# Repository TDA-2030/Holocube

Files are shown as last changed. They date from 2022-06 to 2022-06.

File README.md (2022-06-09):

# Holocubic

用 ESP32-S3 重新设计的版本

## 板载资源

- [ESP32-S3FN8 / ESP32-S3FH4R2](https://www.espressif.com/sites/default/files/documentation/esp32-s3_datasheet_en.pdf)
- [WM8978](https://pdf1.alldatasheet.com/datasheet-pdf/view/96647/WOLFSON/WM8978.html) 音频 Codec
- 单声道模拟麦克风
- MPU6050 惯性传感器

## PCB 

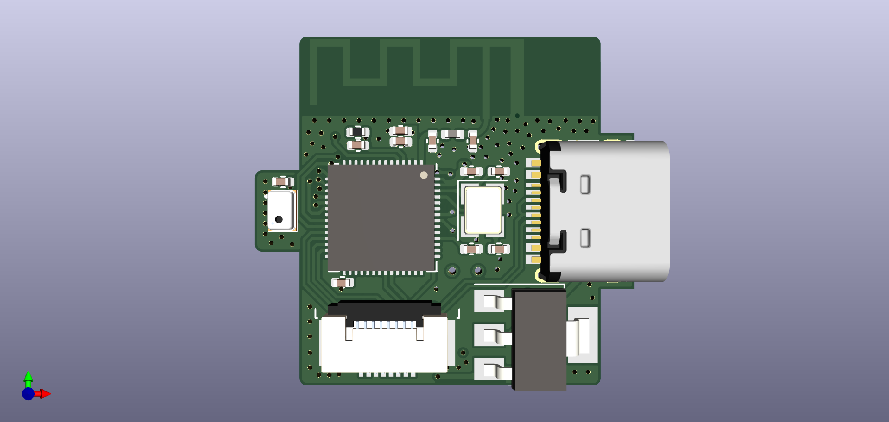
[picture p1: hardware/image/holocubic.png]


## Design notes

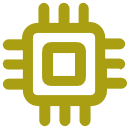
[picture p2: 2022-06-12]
firmware/main/HoloCubic_AIO/Image/app_hardware_info.png

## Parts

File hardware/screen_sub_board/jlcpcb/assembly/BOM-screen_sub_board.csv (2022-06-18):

Comment | Designator | Footprint | LCSC
S8050 | Q1 | SOT-23
22R | R1 | R_0402_1005Metric
Conn_01x08_MountingPin | J1 | TE_0-1734839-8_1x08-1MP_P0.5mm_Horizontal
1uf | C1 | C_0402_1005Metric
LCD_1.3_240x240_ST7789 | U1 | LCD_1.3_240x240_ST7789
10K | R2 | R_0402_1005Metric
1uf | C2 | C_0402_1005Metric

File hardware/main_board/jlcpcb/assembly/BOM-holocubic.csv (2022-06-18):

Comment | Designator | Footprint | LCSC
1uf | C25 | C_0402_1005Metric
0.1uf | C26 | C_0402_1005Metric
2.2uf | C17 | C_0402_1005Metric
AMS1117-3.3 | U1 | SOT-223-3_TabPin2
1uf | C10 | C_0402_1005Metric
Antenna_Shield | AE1 | Texas_SWRA117D_2.4GHz_Left
TBD | C8 | C_0402_1005Metric
TBD | C7 | C_0402_1005Metric
40MHz | Y1 | Crystal_SMD_3225-4Pin_3.2x2.5mm
0.1uf | C3 | C_0402_1005Metric
10pf | C9 | C_0402_1005Metric
10pf | C11 | C_0402_1005Metric
USB_C_Receptacle_USB2.0 | J2 | USB_C_Receptacle_HRO_TYPE-C-31-M-12
TBD | L1 | L_0402_1005Metric
ESP32-S3 | U2 | QFN-56-1EP_7x7mm_P0.4mm_EP5.6x5.6mm
10uf | C2 | C_0603_1608Metric
TFT_LCD | J1 | TE_0-1734839-8_1x08-1MP_P0.5mm_Horizontal
10k | R1 | R_0402_1005Metric
0.1uf | C5 | C_0402_1005Metric
Microphone_MEMS | MK1 | MEMS_MIC_2.75x1.85x0.9mm
0.1uf | C6 | C_0402_1005Metric
10uf | C4 | C_0603_1608Metric
1uf | C14 | C_0402_1005Metric
2.2uf | C21 | C_0402_1005Metric
TestPoint | TP8 | TestPoint_Pad_D1.0mm
TestPoint | TP7 | TestPoint_Pad_D1.0mm
TestPoint | TP3 | TestPoint_Pad_D1.0mm
0Ω | R4 | R_0402_1005Metric
TestPoint | TP4 | TestPoint_Pad_D1.0mm
2.2uf | C19 | C_0402_1005Metric
WM8978 | U3 | QFN-32-1EP_5x5mm_P0.5mm_EP3.3x3.3mm
2.2uf | C23 | C_0402_1005Metric
1uf | C13 | C_0402_1005Metric
5.1k | R2 | R_0402_1005Metric
2.2uf | C20 | C_0402_1005Metric
TestPoint | TP6 | TestPoint_Pad_D1.0mm
TestPoint | TP5 | TestPoint_Pad_D1.0mm
1uf | C15 | C_0402_1005Metric
1uf | C16 | C_0402_1005Metric
10uf | C1 | C_0603_1608Metric
10pf | C12 | C_0402_1005Metric
2.2uf | C22 | C_0402_1005Metric
MPU-6050 | U4 | InvenSense_QFN-24_4x4mm_P0.5mm
TestPoint | TP1 | TestPoint_Pad_D1.0mm
5.1k | R3 | R_0402_1005Metric
TestPoint | TP2 | TestPoint_Pad_D1.0mm
1uf | C24 | C_0402_1005Metric
1uf | C18 | C_0402_1005Metric

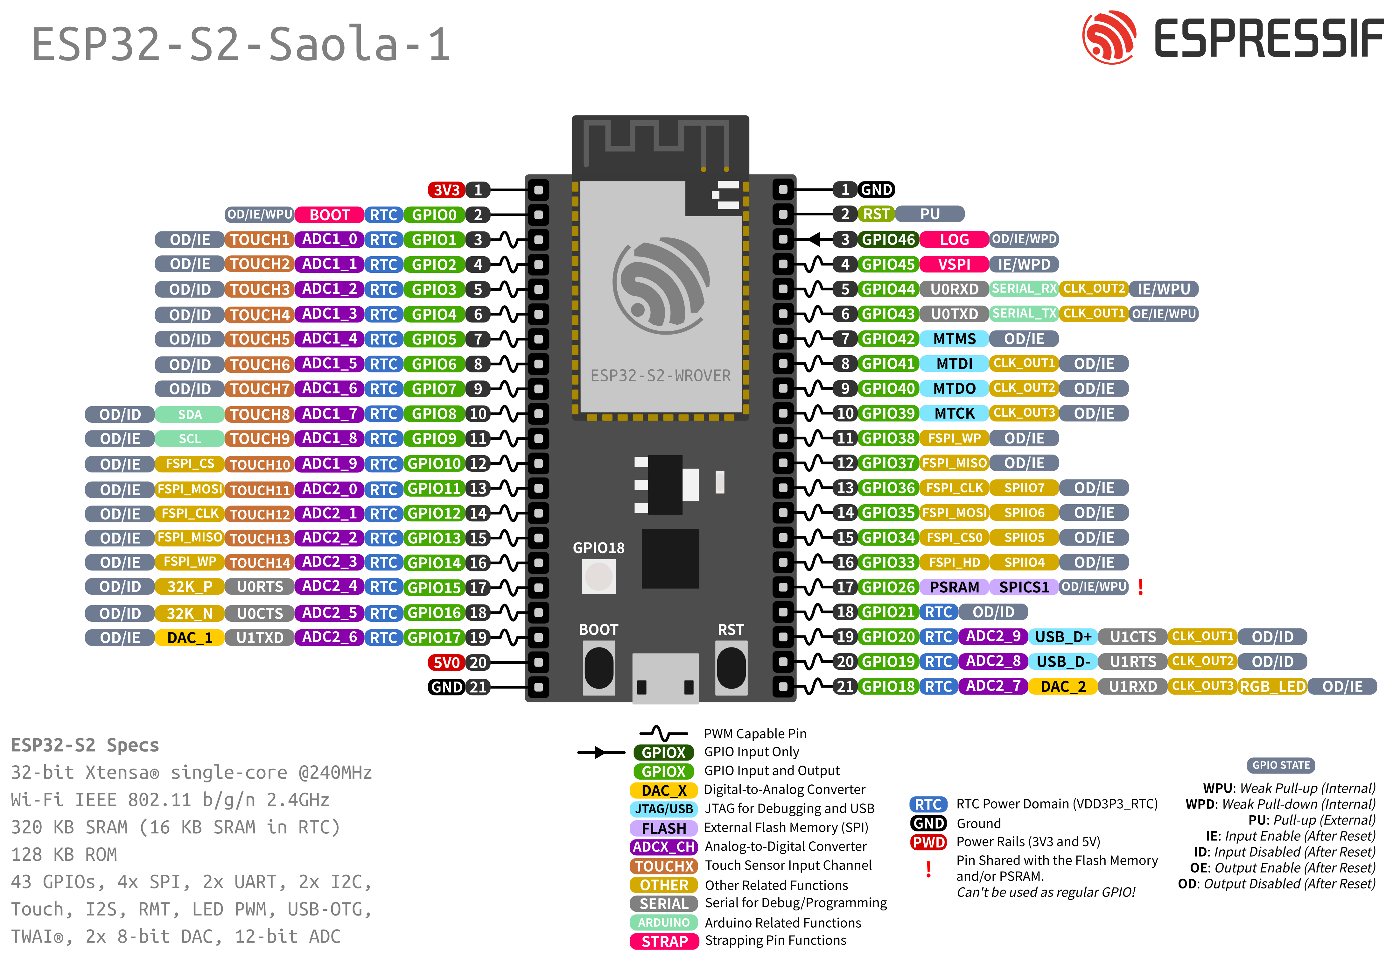
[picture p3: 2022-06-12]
firmware/components/arduino-esp32/docs/source/_static/esp32-s2_saola1_pinlayout.png

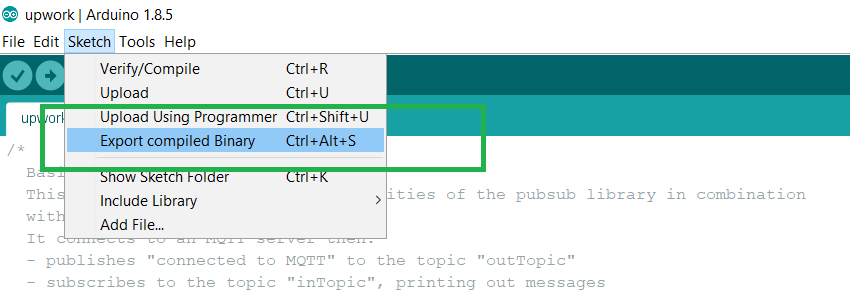
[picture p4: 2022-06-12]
firmware/components/arduino-esp32/docs/source/_static/ota_export_to_binary.png

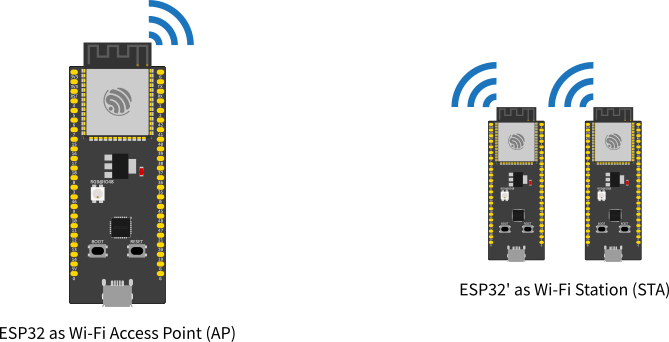
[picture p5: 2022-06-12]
firmware/components/arduino-esp32/docs/source/_static/wifi_esp32_ap.png

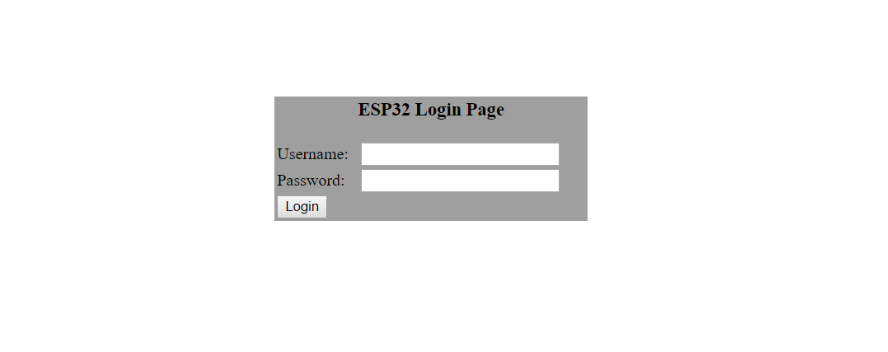
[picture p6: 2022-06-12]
firmware/components/arduino-esp32/docs/source/_static/ota_esp32_login.png

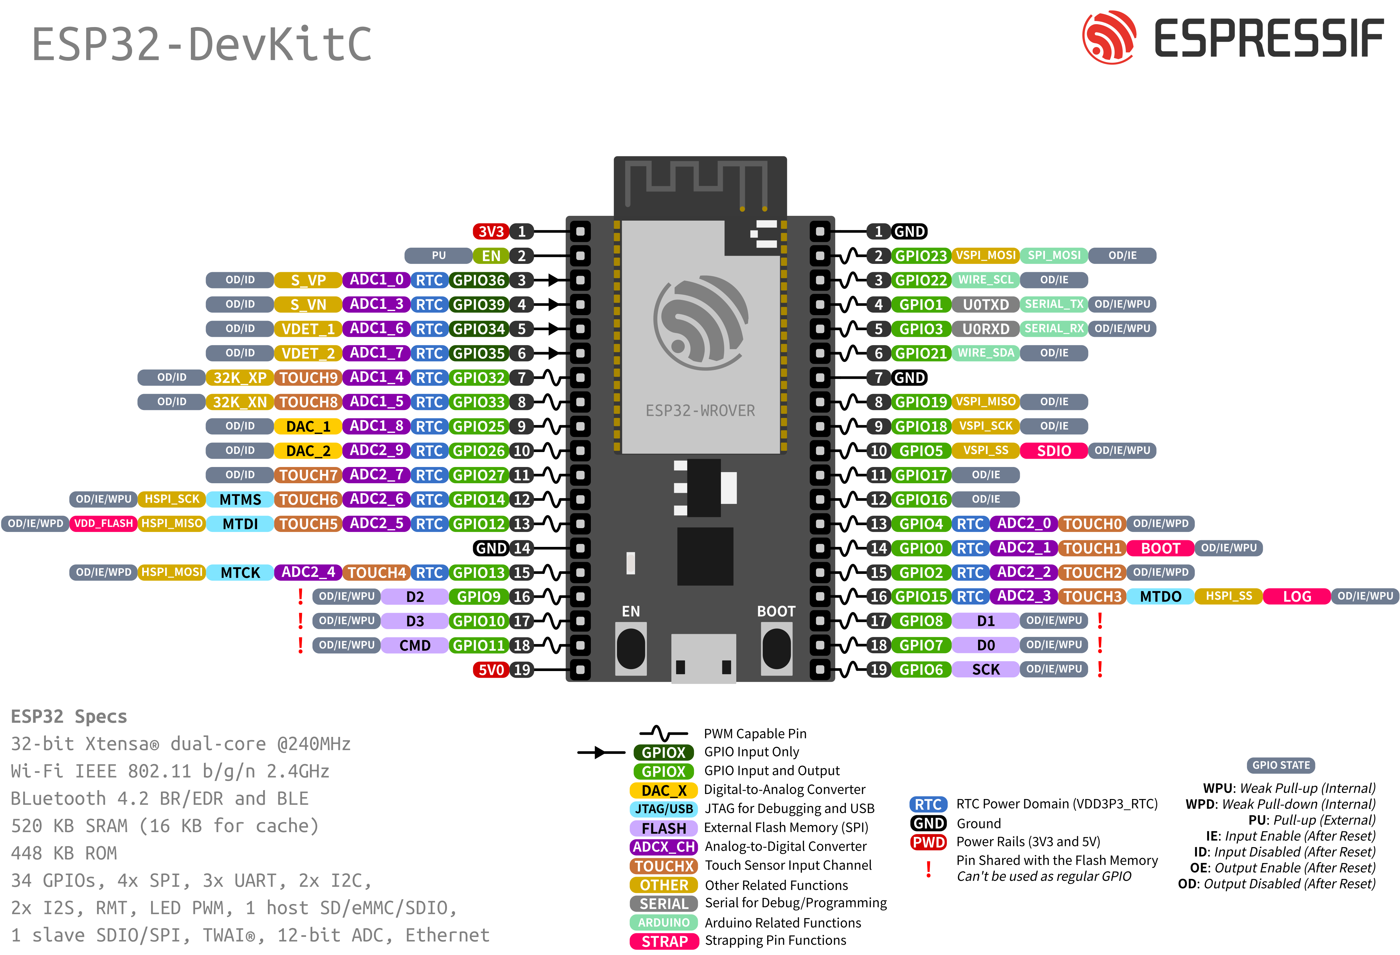
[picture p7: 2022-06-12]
firmware/components/arduino-esp32/docs/source/_static/esp32_devkitC_pinlayout.png

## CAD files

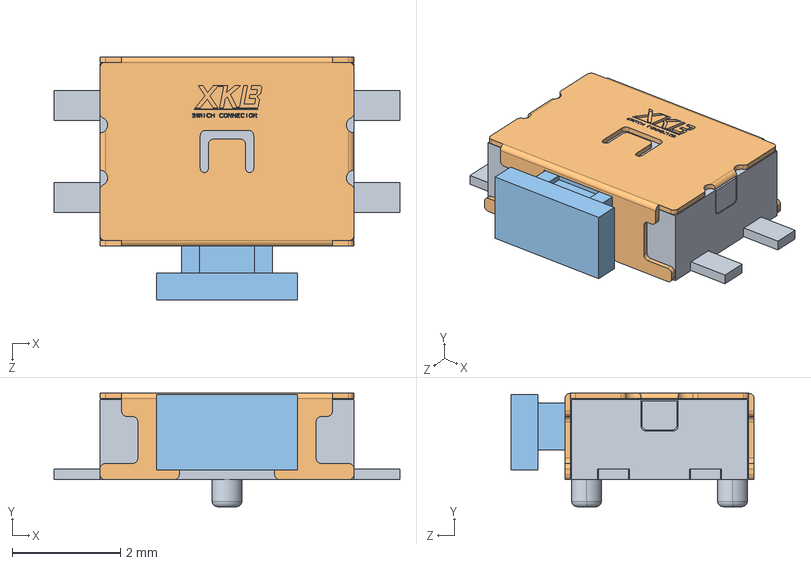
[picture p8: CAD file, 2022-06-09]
hardware/main_board/my-kicad-lib/3d/ts-1186d-c-a.STEP
6.40 x 2.10 x 4.50 mm
ts-1186d-c-a_01
ts-1186d-c-a_02
ts-1186d-c-a_03

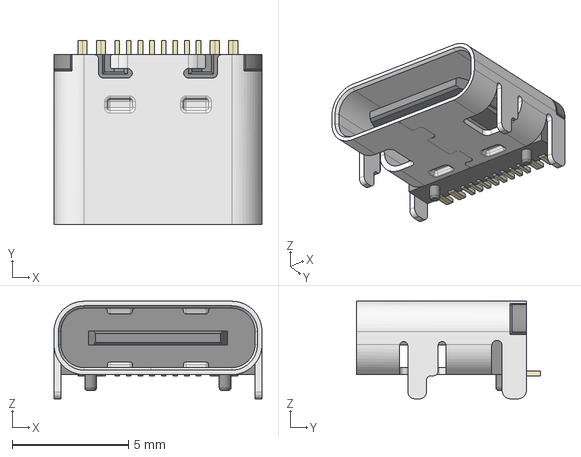
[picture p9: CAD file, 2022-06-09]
hardware/main_board/my-kicad-lib/3d/HRO_TYPE-C-31-M-12.step
8.95 x 7.90 x 4.20 mm

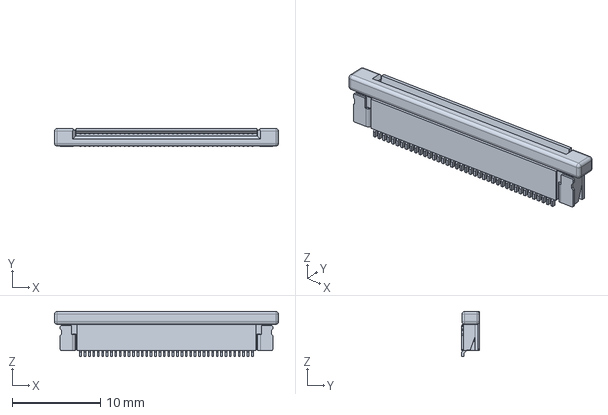
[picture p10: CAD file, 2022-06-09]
hardware/main_board/my-kicad-lib/3d/c-4-1734839-0-c-3d.stp
25.4 x 2.05 x 5.11 mm

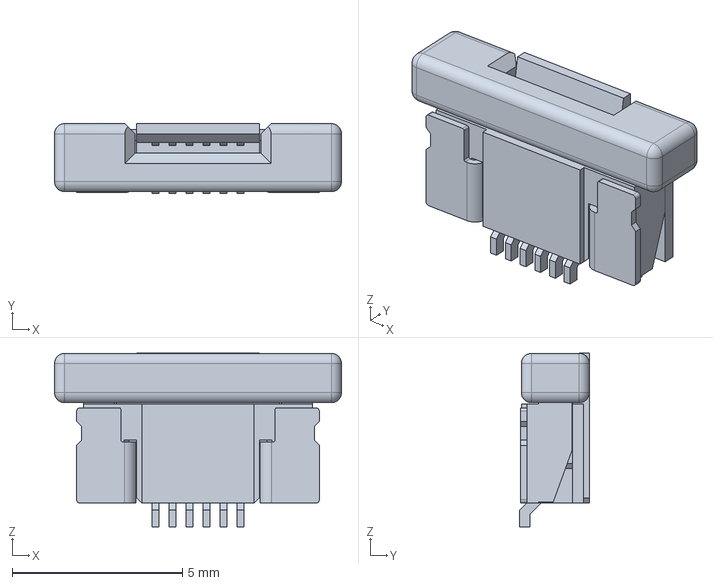
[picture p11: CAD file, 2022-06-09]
hardware/main_board/my-kicad-lib/3d/c-1734839-6-c-3d.stp
8.43 x 2.05 x 5.11 mm

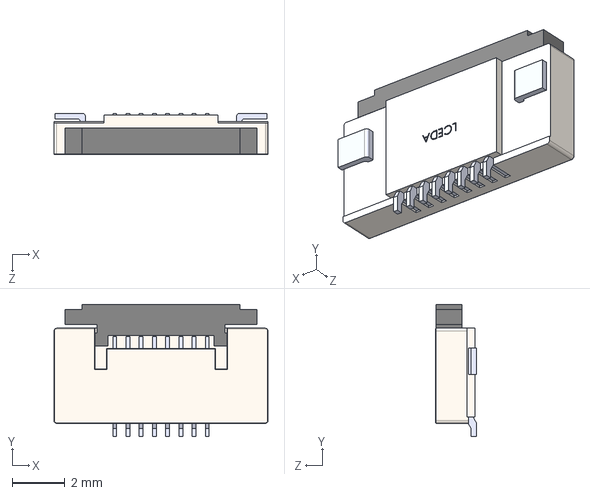
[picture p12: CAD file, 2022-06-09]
hardware/main_board/my-kicad-lib/3d/fpc-8p-0.5mm.STEP
8.10 x 5.00 x 1.55 mm

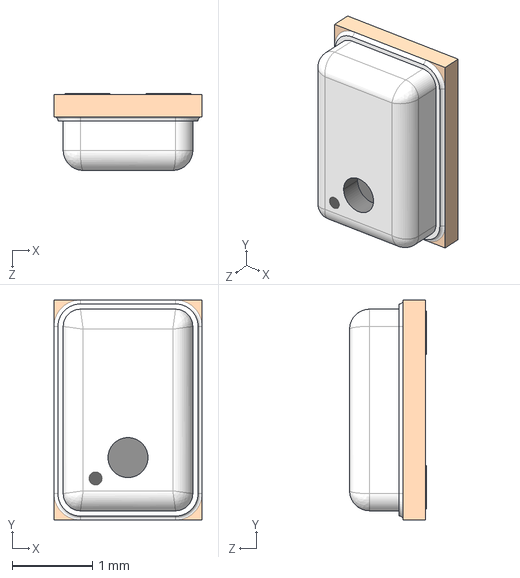
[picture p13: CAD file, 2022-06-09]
hardware/main_board/my-kicad-lib/3d/MEMS_MIC_2.75x1.85x0.95mm.STEP
1.85 x 2.75 x 0.96 mm

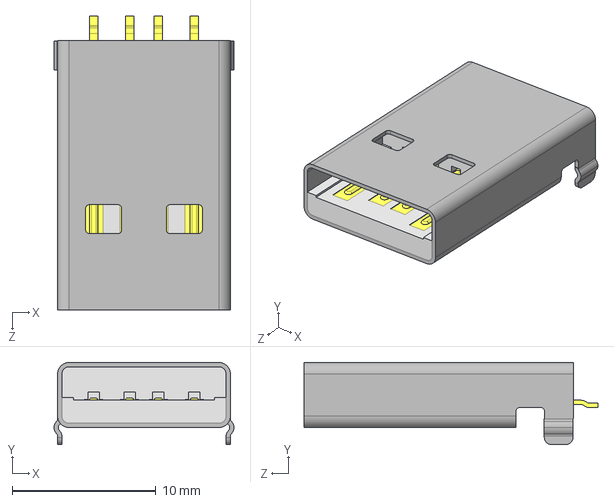
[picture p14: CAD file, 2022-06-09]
hardware/main_board/my-kicad-lib/3d/USB-AM-S-F-B-TH.STEP
12.5 x 5.70 x 20.4 mm

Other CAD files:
firmware/components/libjpeg/jpeg-9a/jdosamsc.obj
firmware/components/libjpeg/jpeg-9a/jdosabcc.obj

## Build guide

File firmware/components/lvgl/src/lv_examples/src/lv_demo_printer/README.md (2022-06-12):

# Printer demo

## Overview
A printer example created with LVGL. This demo is optmized for 800x480 resolution and among many others it demonstrates custom theme creation, style transitions and animations. 

The demo uses some images with 32 bit color depth they require ~1.6 MB flash. With 16 bit color depth ~900KB is required for the images.

Printer demo with LVGL embedded GUI library

## Run the demo
- In `lv_ex_conf.h` set `LV_USE_DEMO_PRINTER 1`
- After `lv_init()` and initializing the drivers call `lv_demo_printer()`

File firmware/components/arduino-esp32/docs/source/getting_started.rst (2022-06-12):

###############
Getting Started
###############

About Arduino ESP32
-------------------

Welcome to the Arduino ESP32 support documentation! Here you will find important information on how to use the project.

First Things First
------------------

.. note::
    Before continuing, we must be clear that this project is supported by `Espressif Systems`_ and the community.
    Everyone is more than welcome to contribute back to this project.

ESP32 is a single 2.4 GHz Wi-Fi-and-Bluetooth SoC (System On a Chip) designed by `Espressif Systems`_.

ESP32 is designed for mobile, wearable electronics, and Internet-of-Things (IoT) applications. It features all the state-of-the-art characteristics 
of low-power chips, including fine-grained clock gating, multiple power modes,and dynamic power scaling. For instance, in a low-power IoT sensor 
hub application scenario, ESP32 is woken-up periodically and only when a specified condition is detected. Low-duty cycle is used to minimize the 
amount of energy that the chip expends. 

The output of the power amplifier is also adjustable, thus contributing to an optimal trade-off between communication range, data rate and 
power consumption.

The ESP32 series is available as a chip or module.

.. _supported_socs:

Supported SoC's
---------------

Here are the ESP32 series supported by the Arduino-ESP32 project:

======== ====== =========== ===================================
SoC      Stable Development Datasheet
======== ====== =========== ===================================
ESP32    Yes    Yes         `ESP32`_
ESP32-S2 Yes    Yes         `ESP32-S2`_
ESP32-C3 Yes    Yes         `ESP32-C3`_
ESP32-S3 No     Yes         `ESP32-S3`_
======== ====== =========== ===================================

See `Boards <boards/boards.html>`_ for more details about ESP32 development boards.

Arduino Core Reference
----------------------

This documentation is built on the ESP32 and we are not going to cover the common Arduino API. To see the Arduino reference documentation, 
please consider reading the official documentation.

Arduino Official Documentation: `Arduino Reference`_.

Supported Operating Systems
---------------------------

+-------------------+-------------------+-------------------+
|     |       |       |
+-------------------+-------------------+-------------------+
| Windows           | Linux             | macOS             |
+-------------------+-------------------+-------------------+





Supported IDEs
---------------------------

Here is the list of supported IDE for Arduino ESP32 support integration.

+-------------------+-------------------+
|     |         |
+-------------------+-------------------+
| Arduino IDE       | PlatformIO        |
+-------------------+-------------------+




See `Installing Guides <installing.html>`_ for more details on how to install the Arduino ESP32 support.

Support
-------

This is an open project and it's supported by the community. Fell free to ask for help in one of the community channels.

Community
---------

The Arduino community is huge! You can find a lot of useful content on the Internet.
Here are some community channels where you may find information and ask for some help, if needed.

- `ESP32 Forum`_: Official Espressif Forum.
- `ESP32 Forum - Arduino`_: Official Espressif Forum for Arduino related discussions.
- `ESP32 Forum - Hardware`_: Official Espressif Forum for Hardware related discussions.
- `Gitter`_
- `Espressif MCUs (Discord)`_
- `ESP32 on Reddit`_

Issues Reporting
----------------

Before opening a new issue, please read this: 

Be sure to search for a similar reported issue. This avoids duplicating or creating noise in the GitHub Issues reporting.
We also have the troubleshooting guide to save your time on the most common issues reported by users.

For more details about creating new Issue, see the `Issue Template <https://github.com/espressif/arduino-esp32/blob/master/.github/ISSUE_TEMPLATE/Issue-report.yml>`_.

If you have any new idea, see the `Feature request Template <https://github.com/espressif/arduino-esp32/blob/master/.github/ISSUE_TEMPLATE/Feature-request.yml>`_.

First Steps
-----------

Here are the first steps to get the Arduino ESP32 support running.

To install Arduino-ESP32, please see the dedicated section on the Installation guide. We recommend you install it using the boards manager.

.. toctree::
    :maxdepth: 2
    
    How to Install <installing>
    Development Boards <boards/boards>

Examples
--------

After installing the toolchain into your environment, you will be able to see all the dedicated examples for the ESP32. These examples are located
in the examples menu or inside each library folder.

    https://github.com/espressif/arduino-esp32/tree/master/libraries

.. include:: common/datasheet.inc

Resources
---------

.. _Espressif Systems: https://www.espressif.com 
.. _Espressif Product Selector: https://products.espressif.com/
.. _Arduino.cc: https://www.arduino.cc/en/Main/Software
.. _Arduino Reference: https://www.arduino.cc/reference/en/
.. _ESP32 Forum: https://esp32.com
.. _ESP32 Forum - Arduino: https://esp32.com/viewforum.php?f=19
.. _ESP32 Forum - Hardware: https://esp32.com/viewforum.php?f=12
.. _Gitter: https://gitter.im/espressif/arduino-esp32
.. _Adafruit (Discord): https://discord.gg/adafruit
.. _Espressif MCUs (Discord): https://discord.gg/nKxMTnkD
.. _ESP32 on Reddit: https://www.reddit.com/r/esp32

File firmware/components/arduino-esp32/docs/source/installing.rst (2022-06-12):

##########
Installing
##########

This guide will show how to install the Arduino-ESP32 support.

Before Installing
-----------------

We recommend you install the support using your favorite IDE, but other options are available depending on your operating system. 
To install Arduino-ESP32 support, you can use one of the following options.

Installing using Arduino IDE
----------------------------



This is the way to install Arduino-ESP32 directly from the Arduino IDE.

.. note::
   For overview of SoC's support, take a look on `Supported Soc's table <https://docs.espressif.com/projects/arduino-esp32/en/latest/getting_started.html#supported-soc-s>`_ where you can find if the particular chip is under stable or development release.

- Stable release link::

   https://raw.githubusercontent.com/espressif/arduino-esp32/gh-pages/package_esp32_index.json

- Development release link::

   https://raw.githubusercontent.com/espressif/arduino-esp32/gh-pages/package_esp32_dev_index.json

.. note::
   Starting with the Arduino IDE version 1.6.4, Arduino allows installation of third-party platform 
   packages using Boards Manager. We have packages available for Windows, macOS, and Linux.

To start the installation process using the Boards Managaer, follow these steps:

-  Install the current upstream Arduino IDE at the 1.8 level or later. The current version is at the `arduino.cc`_ website.

-  Start Arduino and open the Preferences window.



-  Enter one of the release links above into *Additional Board Manager URLs* field. You can add multiple URLs, separating them with commas.



-  Open Boards Manager from Tools > Board menu and install *esp32* platform (and do not forget to select your ESP32 board from Tools > Board menu after installation).



- Restart Arduino IDE.

Installing using PlatformIO
---------------------------



PlatformIO is a professional collaborative platform for embedded development. It has out-of-the-box support for ESP32 SoCs and allows working with Arduino ESP32 as well as ESP-IDF from Espressif without changing your development environment. PlatformIO includes lots of instruments for the most common development tasks such as debugging, unit testing, and static code analysis.

A detailed overview of the PlatformIO ecosystem and its philosophy can be found in `the official documentation <https://docs.platformio.org/en/latest/core/index.html>`_.

PlatformIO can be used in two flavors:

- `PlatformIO IDE <https://platformio.org/platformio-ide>`_ is a toolset for embedded C/C++ development available on Windows, macOS and Linux platforms

- `PlatformIO Core (CLI) <https://docs.platformio.org/en/latest/core/index.html>`_ is a command-line tool that consists of a multi-platform build system, platform and library managers and other integration components. It can be used with a variety of code development environments and allows integration with cloud platforms and web services

To install PlatformIO, you can follow this Getting Started, provided at `docs.platformio.org`_.

Using the stable code
*********************

.. note::
   A detailed overview of supported development boards, examples and frameworks can be found on `the official Espressif32 dev-platform page <https://registry.platformio.org/platforms/platformio/espressif32>`_ in the PlatformIO Registry.

The most reliable and easiest way to get started is to use the latest stable version of the ESP32 development platform that passed all tests/verifications and can be used in production.

Create a new project and select one of the available boards. You can change after by changing the `platformio.ini <https://docs.platformio.org/en/latest/projectconf/index.html>`_ file.

- For ESP32

.. code-block:: bash

   [env:esp32dev]
   platform = espressif32
   board = esp32dev
   framework = arduino

- For ESP32-S2 (ESP32-S2-Saola-1 board)

.. code-block:: bash

   [env:esp32-s2-saola-1]
   platform = espressif32
   board = esp32-s2-saola-1
   framework = arduino

- For ESP32-C3 (ESP32-C3-DevKitM-1 board)

.. code-block:: bash

   [env:esp32-c3-devkitm-1]
   platform = espressif32
   board = esp32-c3-devkitm-1
   framework = arduino

How to update to the latest code
********************************

To test the latest Arduino ESP32, you need to change your project *platformio.ini* accordingly.
The following configuration uses the upstream version of the Espressif development platform and the latest Arduino core directly from the Espressif GitHub repository:

.. code-block:: bash

   [env:esp32-c3-devkitm-1]
   platform = https://github.com/platformio/platform-espressif32.git
   board = esp32-c3-devkitm-1
   framework = arduino
   platform_packages =
       framework-arduinoespressif32 @ https://github.com/espressif/arduino-esp32#master

To get more information about PlatformIO, see the following links:

- `PlatformIO Core (CLI) <https://docs.platformio.org/en/latest/core/index.html>`_

- `PlatformIO Home <https://docs.platformio.org/en/latest/home/index.html>`_

- `Tutorials and Examples <https://docs.platformio.org/en/latest/tutorials/index.html>`_

- `Library Management <https://docs.platformio.org/en/latest/librarymanager/index.html>`_

Windows (manual installation)
-----------------------------

.. warning:: Arduino ESP32 core v2.x.x cannot be used on Windows 8.x x86 (32 bits), Windows 7 or earlier. The Windows 32 bits OS is no longer supported by this toolchain.

   The Arduino ESP32 v1.0.6 still works on WIN32. You might want to install python 3.8.x because it is the latest release supported by Windows 7.

Steps to install Arduino ESP32 support on Windows:

**Step 1**

1. Download and install the latest Arduino IDE ``Windows Installer`` from [arduino.cc](https://www.arduino.cc/en/Main/Software)
2. Download and install Git from [git-scm.com](https://git-scm.com/download/win)
3. Start ``Git GUI`` and do the following steps:

- Select ``Clone Existing Repository``



- Select source and destination
   - Sketchbook Directory: Usually ``C:/Users/[YOUR_USER_NAME]/Documents/Arduino`` and is listed underneath the "Sketchbook location" in Arduino preferences.
   - Source Location: ``https://github.com/espressif/arduino-esp32.git``
   - Target Directory: ``[ARDUINO_SKETCHBOOK_DIR]/hardware/espressif/esp32``
   - Click ``Clone`` to start cloning the repository

**Step 2**



**Step 3**



- open a `Git Bash` session pointing to ``[ARDUINO_SKETCHBOOK_DIR]/hardware/espressif/esp32`` and execute ```git submodule update --init --recursive``` 
- Open ``[ARDUINO_SKETCHBOOK_DIR]/hardware/espressif/esp32/tools`` and double-click ``get.exe``

**Step 4**



- When ```get.exe``` finishes, you should see the following files in the directory

**Step 5**



1. Plug your ESP32 board and wait for the drivers to install (or install manually any that might be required)
2. Start Arduino IDE
3. Select your board in ``Tools > Board`` menu
4. Select the COM port that the board is attached to
5. Compile and upload (You might need to hold the boot button while uploading)



How to update to the latest code
********************************

1. Start ``Git GUI`` and you should see the repository under ``Open Recent Repository``. Click on it!



1. From menu ``Remote`` select ``Fetch from`` > ``origin``



1. Wait for git to pull any changes and close ``Git GUI``
2. Open ``[ARDUINO_SKETCHBOOK_DIR]/hardware/espressif/esp32/tools`` and double-click ``get.exe``



Linux
-----



Debian/Ubuntu
*************

- Install latest Arduino IDE from `arduino.cc`_.

- Open Terminal and execute the following command (copy -> paste and hit enter):

.. code-block:: bash

   sudo usermod -a -G dialout $USER && \
   sudo apt-get install git && \
   wget https://bootstrap.pypa.io/get-pip.py && \
   sudo python3 get-pip.py && \
   sudo pip3 install pyserial && \
   mkdir -p ~/Arduino/hardware/espressif && \
   cd ~/Arduino/hardware/espressif && \
   git clone https://github.com/espressif/arduino-esp32.git esp32 && \
   cd esp32/tools && \
   python3 get.py

- Restart Arduino IDE.

- If you have Arduino installed to ~/, modify the installation as follows, beginning at `mkdir -p ~/Arduino/hardware`:

.. code-block:: bash

   cd ~/Arduino/hardware
   mkdir -p espressif && \
   cd espressif && \
   git clone https://github.com/espressif/arduino-esp32.git esp32 && \
   cd esp32/tools && \
   python3 get.py

Fedora
******

- Install the latest Arduino IDE from `arduino.cc`_.

.. note::
   Command ``$ sudo dnf -y install arduino`` will most likely install an older release.

- Open Terminal and execute the following command (copy -> paste and hit enter):

.. code-block:: bash

   sudo usermod -a -G dialout $USER && \
   sudo dnf install git python3-pip python3-pyserial && \
   mkdir -p ~/Arduino/hardware/espressif && \
   cd ~/Arduino/hardware/espressif && \
   git clone https://github.com/espressif/arduino-esp32.git esp32 && \
   cd esp32/tools && \
   python get.py

- Restart Arduino IDE.

openSUSE
********

- Install the latest Arduino IDE from `arduino.cc`_.

- Open Terminal and execute the following command (copy -> paste and hit enter):

.. code-block:: bash

   sudo usermod -a -G dialout $USER && \
   if [ `python --version 2>&1 | grep '2.7' | wc -l` = "1" ]; then \
   sudo zypper install git python-pip python-pyserial; \
   else \
   sudo zypper install git python3-pip python3-pyserial; \
   fi && \
   mkdir -p ~/Arduino/hardware/espressif && \
   cd ~/Arduino/hardware/espressif && \
   git clone https://github.com/espressif/arduino-esp32.git esp32 && \
   cd esp32/tools && \
   python get.py

- Restart Arduino IDE.

macOS
-----

- Install the latest Arduino IDE from `arduino.cc`_.

- Open Terminal and execute the following command (copy -> paste and hit enter):

.. code-block:: bash

   mkdir -p ~/Documents/Arduino/hardware/espressif && \
   cd ~/Documents/Arduino/hardware/espressif && \
   git clone https://github.com/espressif/arduino-esp32.git esp32 && \
   cd esp32/tools && \
   python get.py 

Where ``~/Documents/Arduino`` represents your sketch book location as per "Arduino" > "Preferences" > "Sketchbook location" (in the IDE once started). Adjust the command above accordingly.

- If you get the error below, install through the command line dev tools with `xcode-select --install` and try the command above again:

.. code-block:: bash

   xcrun: error: invalid active developer path (/Library/Developer/CommandLineTools), missing xcrun at: /Library/Developer/CommandLineTools/usr/bin/xcrun

- Run the command:

.. code-block:: bash

   xcode-select --install

- Try ``python3`` instead of ``python`` if you get the error: ``IOError: [Errno socket error] [SSL: TLSV1_ALERT_PROTOCOL_VERSION] tlsv1 alert protocol version (_ssl.c:590)`` when running ``python get.py``

- If you get the following error when running ``python get.py`` urllib.error.URLError: <urlopen error SSL: CERTIFICATE_VERIFY_FAILED, go to Macintosh HD > Applications > Python3.6 folder (or any other python version), and run the following scripts: Install Certificates.command and Update Shell Profile.command

- Restart Arduino IDE.

.. _Arduino.cc: https://www.arduino.cc/en/Main/Software
.. _docs.platformio.org: https://docs.platformio.org/en/latest/integration/ide/pioide.html

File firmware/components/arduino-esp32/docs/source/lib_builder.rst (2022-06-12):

###############
Library Builder
###############

About
-----

Espressif provides a `tool <https://github.com/espressif/esp32-arduino-lib-builder>`_ to simplify building your own compiled libraries for use in Arduino IDE (or your favorite IDE).

This tool can be used to change the project or a specific configuration according to your needs.

Installing
----------

To install the Library Builder into your environment, please, follow the instructions below.

- Clone the ESP32 Arduino lib builder:

.. code-block:: bash

    git clone https://github.com/espressif/esp32-arduino-lib-builder

- Go to the ``esp32-arduino-lib-builder`` folder:

.. code-block:: bash

    cd esp32-arduino-lib-builder

- Build:

.. code-block:: bash

    ./build.sh

If everything works, you may see the following message: ``Successfully created esp32 image.``

Dependencies
************

To build the library you will need to install some dependencies. Maybe you already have installed it, but it is a good idea to check before building.

- Install all dependencies (**Ubuntu**):

.. code-block:: bash

    sudo apt-get install git wget curl libssl-dev libncurses-dev flex bison gperf cmake ninja-build ccache jq

- Install Python and upgrade pip:

.. code-block:: bash

    sudo apt-get install python3
    sudo pip install --upgrade pip

- Install all required packages:

.. code-block:: bash

    pip install --user setuptools pyserial click cryptography future pyparsing pyelftools

Building
--------

If you have all the dependencies met, it is time to build the libraries.

To build using the default configuration:

.. code-block:: bash

    ./build.sh

Custom Build
************

There are some options to help you create custom libraries. You can use the following options:

Usage
^^^^^

.. code-block:: bash

    build.sh [-s] [-A arduino_branch] [-I idf_branch] [-i idf_commit] [-c path] [-t <target>] [-b <build|menuconfig|idf_libs|copy_bootloader|mem_variant>] [config ...]

Skip Install/Update
^^^^^^^^^^^^^^^^^^^

Skip installing/updating of ESP-IDF and all components

.. code-block:: bash

    ./build.sh -s

This option can be used if you already have the ESP-IDF and all components already in your environment.

Set Arduino-ESP32 Branch
^^^^^^^^^^^^^^^^^^^^^^^^

Set which branch of arduino-esp32 to be used for compilation

.. code-block:: bash

    ./build.sh -A <arduino_branch>

Set ESP-IDF Branch
^^^^^^^^^^^^^^^^^^

Set which branch of ESP-IDF is to be used for compilation

.. code-block:: bash

    ./build.sh -I <idf_branch>

Set the ESP-IDF Commit
^^^^^^^^^^^^^^^^^^^^^^

Set which commit of ESP-IDF to be used for compilation

.. code-block:: bash

    ./build.sh -i <idf_commit>

Deploy
^^^^^^

Deploy the build to github arduino-esp32

.. code-block:: bash

    ./build.sh -d

Set the Arduino-ESP32 Destination Folder
^^^^^^^^^^^^^^^^^^^^^^^^^^^^^^^^^^^^^^^^

Set the arduino-esp32 folder to copy the result to. ex. '$HOME/Arduino/hardware/espressif/esp32'

.. code-block:: bash

    ./build.sh -c <path>

This function is used to copy the compiled libraries to the Arduino folder.

Set the Target
^^^^^^^^^^^^^^

Set the build target(chip). ex. 'esp32s3'

.. code-block:: bash

    ./build.sh -t <target>

This build command will build for the ESP32-S3 target. You can specify other targets.

* esp32
* esp32s2
* esp32c3
* esp32s3

Set Build Type
^^^^^^^^^^^^^^

Set the build type. ex. 'build' to build the project and prepare for uploading to a board.

.. note:: This command depends on the ``-t`` argument.

.. code-block:: bash

    ./build.sh -t esp32 -b <build|menuconfig|idf_libs|copy_bootloader|mem_variant>

Additional Configuration
^^^^^^^^^^^^^^^^^^^^^^^^

Specify additional configs to be applied. ex. 'qio 80m' to compile for QIO Flash@80MHz. Requires -b

.. note:: This command requires the ``-b`` to work properly.

.. code-block:: bash

    ./build.sh -t esp32 -b idf_libs qio 80m

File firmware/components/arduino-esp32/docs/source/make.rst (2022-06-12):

==============
makeEspArduino
==============

The `makeEspArduino <https://github.com/plerup/makeEspArduino>`_ is a generic makefile for any ESP8266/ESP32 Arduino project. 
Using it instead of the Arduino IDE makes it easier to do automated and production builds.

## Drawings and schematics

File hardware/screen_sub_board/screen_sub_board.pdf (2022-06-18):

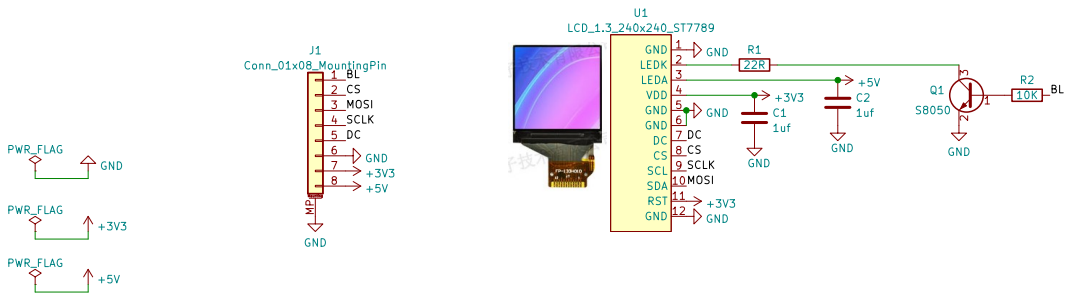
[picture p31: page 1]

2 3 Q1 S8050 GND 1 SDA 10 RST 11 GND 12

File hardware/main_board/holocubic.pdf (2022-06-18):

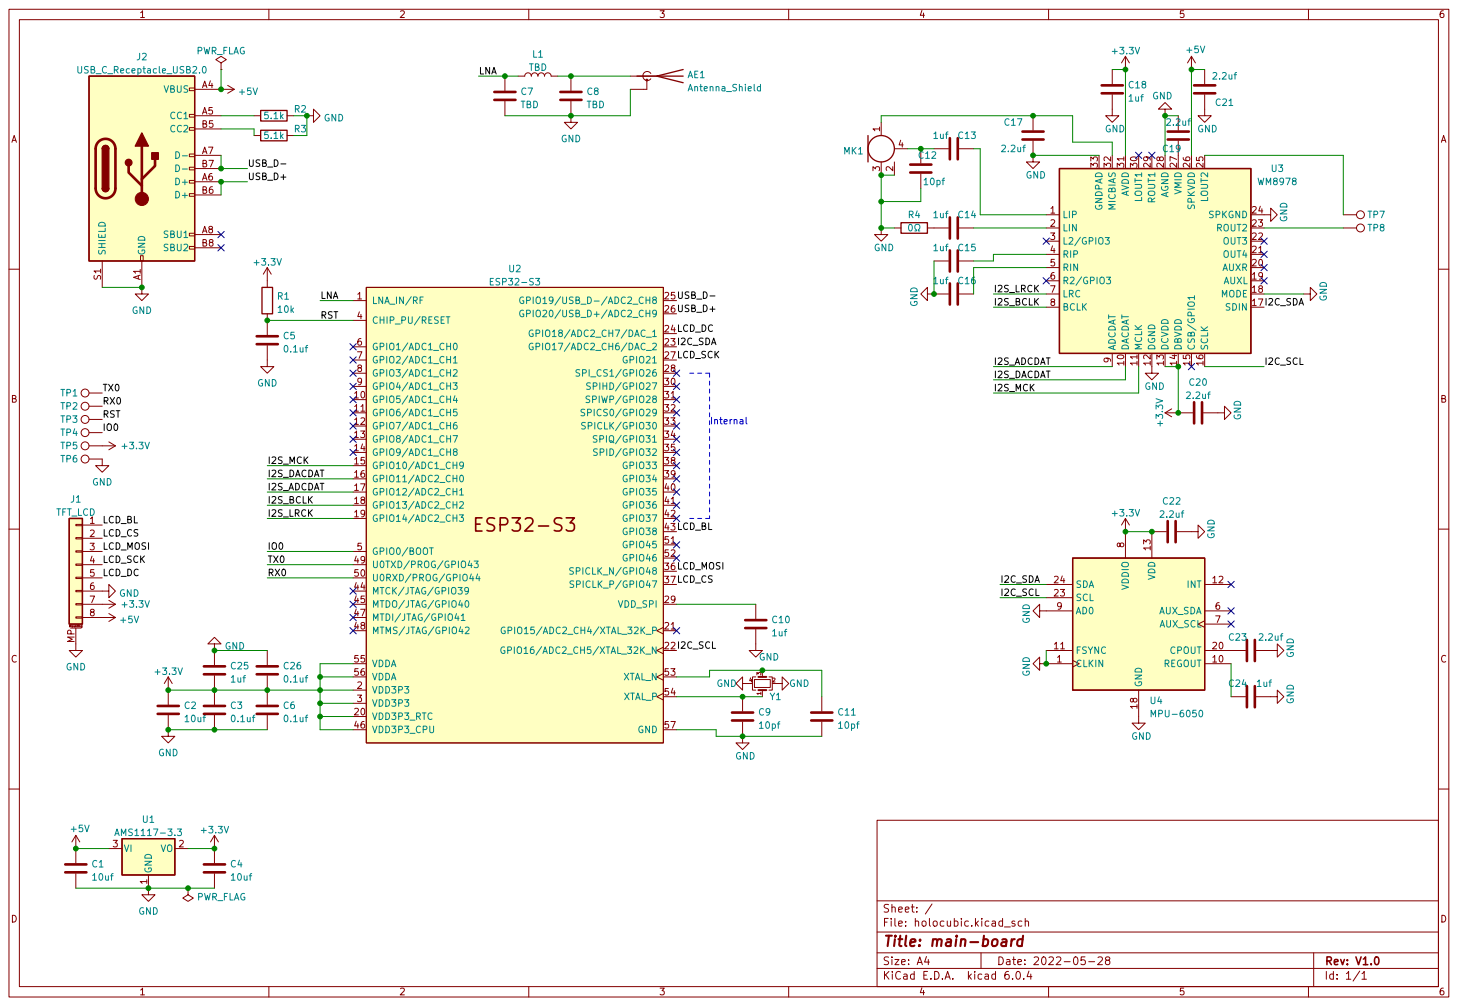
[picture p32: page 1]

File: holocubic.kicad_sch Sheet: /
Id: 1/1 Title: main-board

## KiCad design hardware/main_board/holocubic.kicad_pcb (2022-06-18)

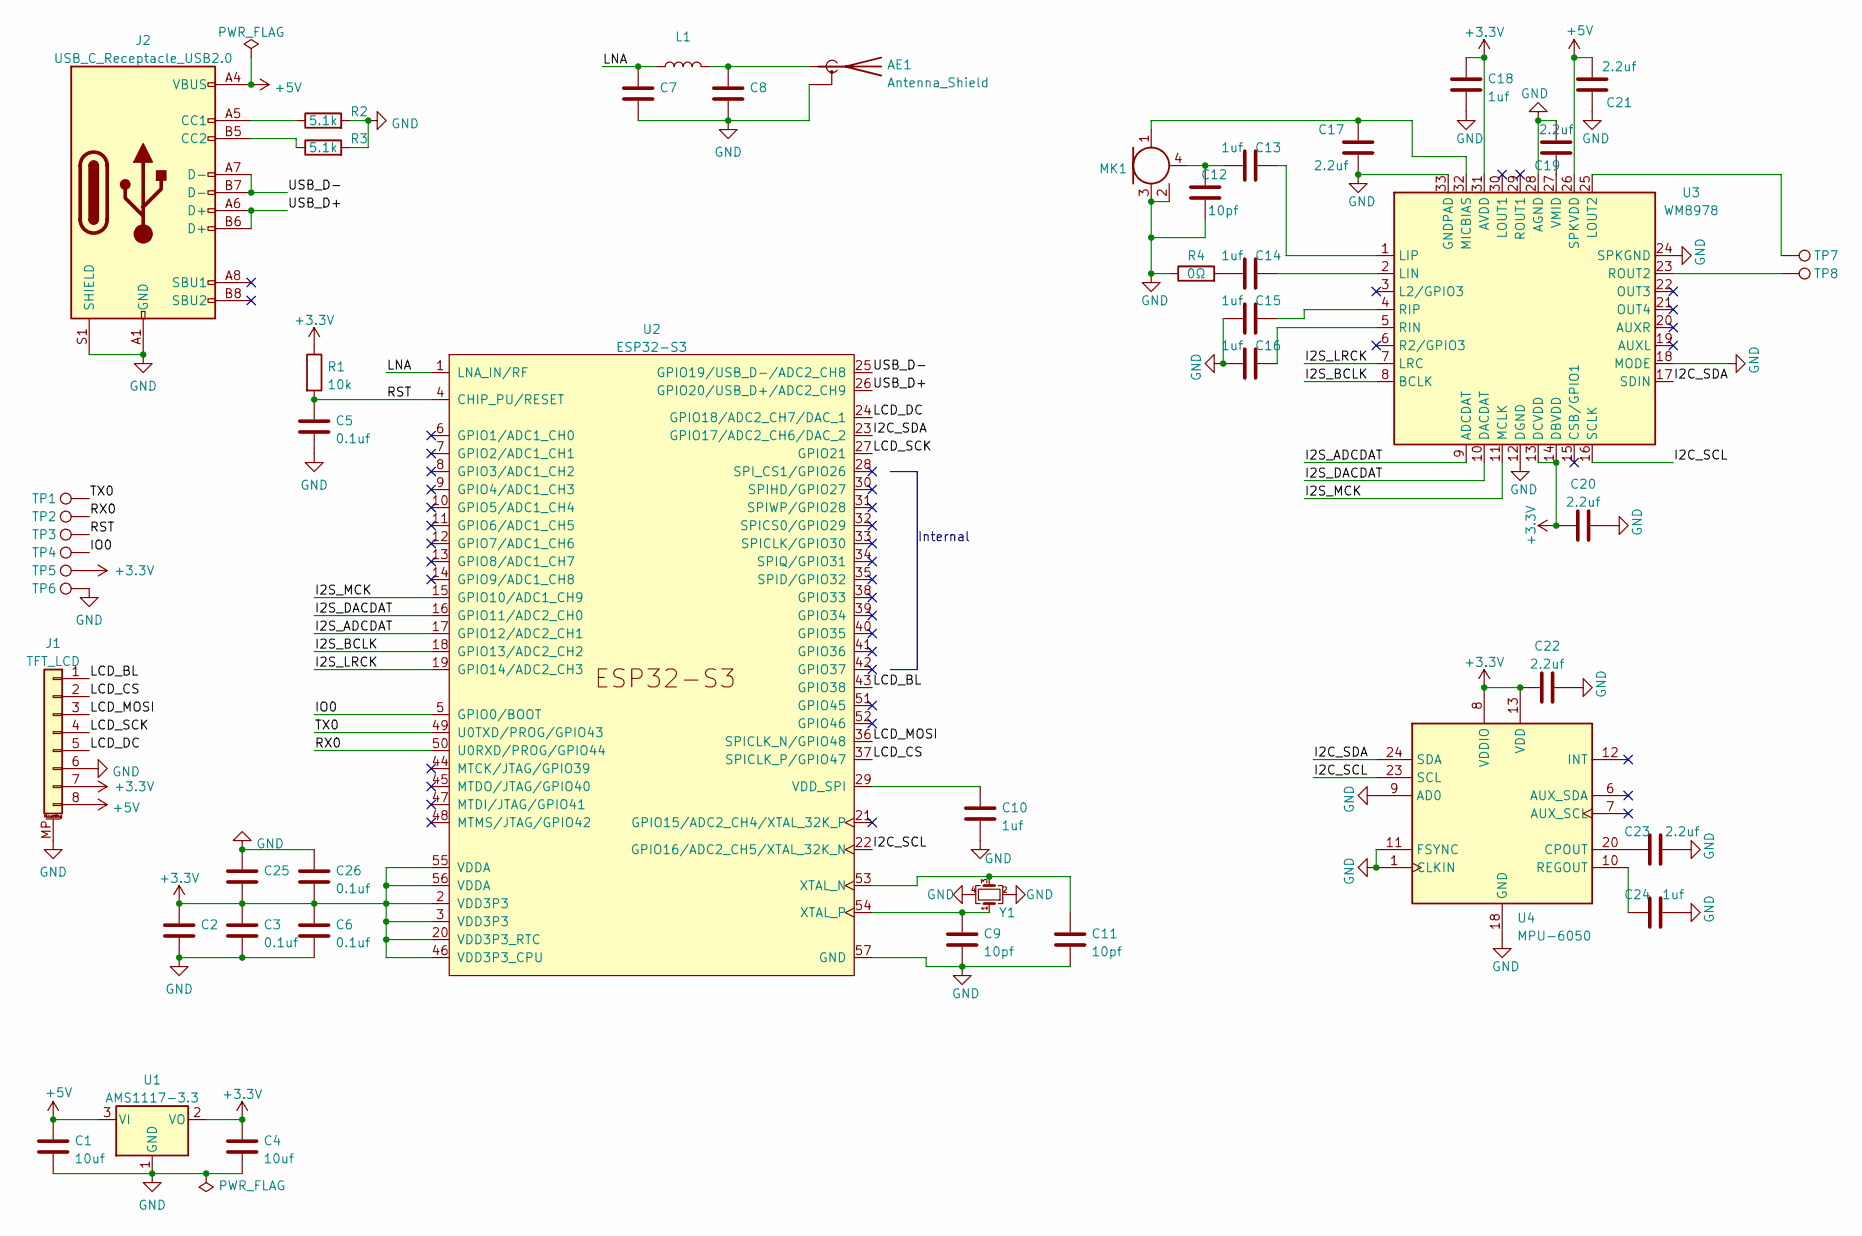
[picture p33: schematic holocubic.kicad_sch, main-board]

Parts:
AE1: Antenna_Shield; Texas_SWRA117D_2.4GHz_Left
C1, C4: 10uf; C_0603_1608Metric
C2: C_0603_1608Metric
C3, C5, C6, C26: 0.1uf; C_0402_1005Metric
C7, C8: C_0402_1005Metric
C9, C11, C12: 10pf; C_0402_1005Metric
C10, C13, C14, C15, C16, C18, C24: 1uf; C_0402_1005Metric
C17, C19, C20, C21, C22, C23: 2.2uf; C_0402_1005Metric
C25: (no value)
J1: TFT_LCD; TE_0-1734839-8_1x08-1MP_P0.5mm_Horizontal
J2: USB_C_Receptacle_USB2.0; USB_C_Receptacle_HRO_TYPE-C-31-M-12
L1: L_0402_1005Metric
MK1: Microphone_MEMS; MEMS_MIC_2.75x1.85x0.9mm
R1: 10k; R_0402_1005Metric
R2, R3: 5.1k; R_0402_1005Metric
R4: 0Ω; R_0402_1005Metric
TP1, TP2, TP3, TP4, TP5, TP6, TP7, TP8: TestPoint; TestPoint_Pad_D1.0mm
U1: AMS1117-3.3; SOT-223-3_TabPin2
U2: ESP32-S3; QFN-56-1EP_7x7mm_P0.4mm_EP5.6x5.6mm
U3: WM8978; QFN-32-1EP_5x5mm_P0.5mm_EP3.3x3.3mm
U4: MPU-6050; InvenSense_QFN-24_4x4mm_P0.5mm
Y1: 40MHz; Crystal_SMD_3225-4Pin_3.2x2.5mm

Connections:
+3V3: C2.1, C3.1, C4.1, C6.1, C18.1, C20.2, C22.2, C25.2, C26.2, J1.7, R1.1, TP5.1, U1.2 (VO), U2.2 (VDD3P3), U2.3 (VDD3P3), U2.20 (VDD3P3_RTC), U2.46 (VDD3P3_CPU), U2.55 (VDDA), U2.56 (VDDA), U3.13 (DCVDD), U3.14 (DBVDD), U3.31 (AVDD), U4.8 (VDDIO), U4.13 (VDD)
+5V: C1.1, C21.2, J1.8, J2.A4 (VBUS), J2.A9 (VBUS), J2.B4 (VBUS), J2.B9 (VBUS), U1.3 (VI), U3.26 (SPKVDD)
/I2C_SCL: U2.22 (GPIO16/ADC2_CH5/XTAL_32K_N), U3.16 (SCLK), U4.23 (SCL)
/I2C_SDA: U2.23 (GPIO17/ADC2_CH6/DAC_2), U3.17 (SDIN), U4.24 (SDA)
/I2S_ADCDAT: U2.17 (GPIO12/ADC2_CH1), U3.9 (ADCDAT)
/I2S_BCLK: U2.18 (GPIO13/ADC2_CH2), U3.8 (BCLK)
/I2S_DACDAT: U2.16 (GPIO11/ADC2_CH0), U3.10 (DACDAT)
/I2S_LRCK: U2.19 (GPIO14/ADC2_CH3), U3.7 (LRC)
/I2S_MCK: U2.15 (GPIO10/ADC1_CH9), U3.11 (MCLK)
/IO0: TP4.1, U2.5 (GPIO0/BOOT)
/LCD_BL: J1.1, U2.43 (GPIO38)
/LCD_CS: J1.2, U2.37 (SPICLK_P/GPIO47)
/LCD_DC: J1.5, U2.24 (GPIO18/ADC2_CH7/DAC_1)
/LCD_MOSI: J1.3, U2.36 (SPICLK_N/GPIO48)
/LCD_SCK: J1.4, U2.27 (GPIO21)
/LNA: C7.1, L1.1, U2.1 (LNA_IN/RF)
/RST: C5.1, R1.2, TP3.1, U2.4 (CHIP_PU/RESET)
/RX0: TP2.1, U2.50 (U0RXD/PROG/GPIO44)
/TX0: TP1.1, U2.49 (U0TXD/PROG/GPIO43)
/USB_D+: J2.A6 (D+), J2.B6 (D+), U2.26 (GPIO20/USB_D+/ADC2_CH9)
/USB_D-: J2.A7 (D-), J2.B7 (D-), U2.25 (GPIO19/USB_D-/ADC2_CH8)
GND: AE1.2 (Shield), C1.2, C2.2, C3.2, C4.2, C5.2, C6.2, C7.2, C8.2, C9.2, C10.2, C11.2, C12.1, C15.1, C16.1, C17.2, C18.2, C19.2, C20.1, C21.1, C22.1, C23.1, C24.1, C25.1, C26.1, J1.6, J1.MP (MountPin), J2.A1 (GND), J2.A12 (GND), J2.B1 (GND), J2.B12 (GND), J2.S1 (SHIELD), MK1.2 (GND), MK1.3 (GND), R2.2, R3.2, R4.1, TP6.1, U1.1 (GND), U2.57 (GND), U3.12 (DGND), U3.18 (MODE), U3.24 (SPKGND), U3.28 (AGND), U3.33 (GNDPAD), U4.1 (CLKIN), U4.9 (AD0), U4.11 (FSYNC), U4.18 (GND), Y1.2, Y1.4; also elsewhere on the board
unnamed: AE1.1 (A), C8.1, L1.2
unnamed: C9.1, U2.54 (XTAL_P), Y1.1
unnamed: C10.1, U2.29 (VDD_SPI)
unnamed: C11.1, U2.53 (XTAL_N), Y1.3
unnamed 26: C12.2, C13.1, MK1.4 (OUT); also elsewhere on the board
unnamed: C13.2, U3.1 (LIP)
unnamed: C14.1, R4.2
unnamed: C14.2, U3.2 (LIN)
unnamed: C15.2, U3.4 (RIP)
unnamed: C16.2, U3.5 (RIN)
unnamed 32: C17.1, MK1.1 (VDD), U3.32 (MICBIAS); also elsewhere on the board
unnamed: C19.1, U3.27 (VMID)
unnamed: C23.2, U4.20 (CPOUT)
unnamed: C24.2, U4.10 (REGOUT)
unnamed: J2.A5 (CC1), R2.1
unnamed: J2.B5 (CC2), R3.1
unnamed: TP7.1, U3.25 (LOUT2)
unnamed: TP8.1, U3.23 (ROUT2)

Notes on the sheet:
Internal

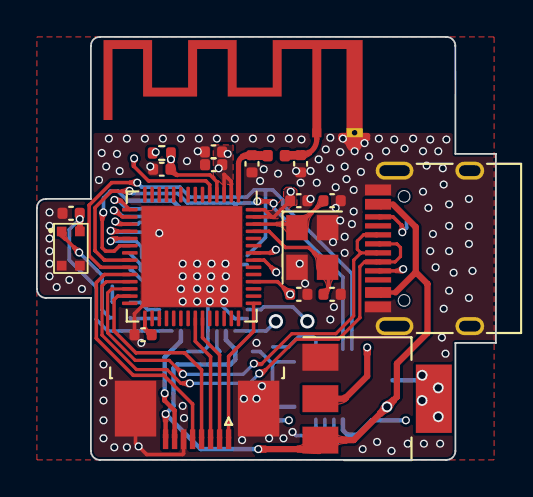
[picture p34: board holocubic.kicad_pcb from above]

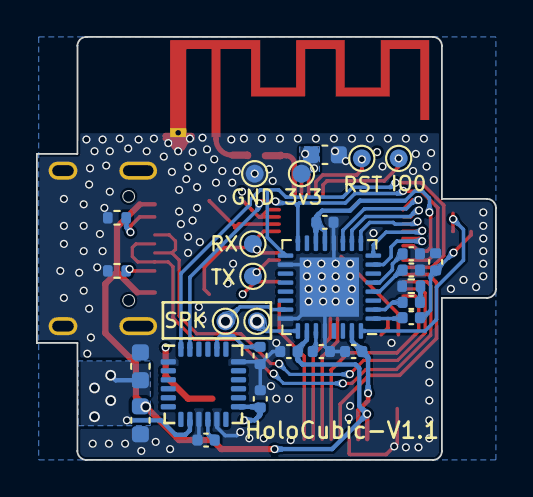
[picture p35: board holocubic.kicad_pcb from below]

Board: 4 copper layers, 25.5 x 23.5 mm, 48 parts (28 on the bottom side), 40 nets.

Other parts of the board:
MK?: Microphone_MEMS; MEMS_MIC_2.75x1.85x0.9mm

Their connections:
GND: MK?.2 (GND), MK?.3 (GND); also elsewhere on the board
unnamed 26: MK?.4 (OUT); also elsewhere on the board
unnamed 32: MK?.1 (VDD); also elsewhere on the board

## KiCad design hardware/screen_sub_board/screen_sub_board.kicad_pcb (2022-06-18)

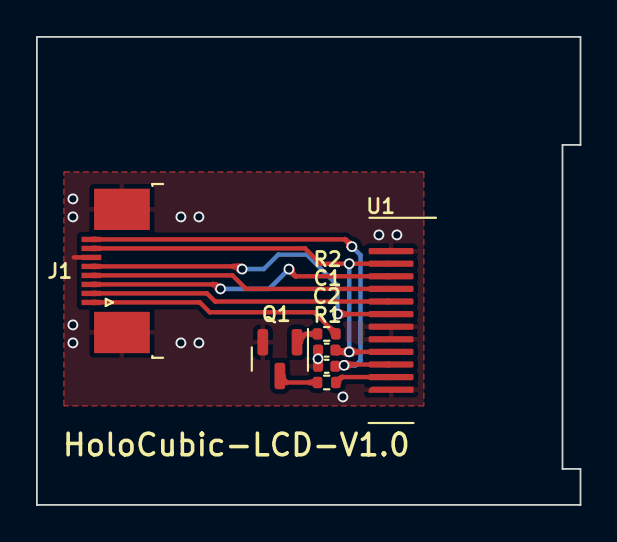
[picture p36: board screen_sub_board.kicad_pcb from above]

Board: 2 copper layers, 30.2 x 26.0 mm, 7 parts (0 on the bottom side), 11 nets.

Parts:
C1, C2: 1uf; C_0402_1005Metric
J1: Conn_01x08_MountingPin; TE_0-1734839-8_1x08-1MP_P0.5mm_Horizontal
Q1: S8050; SOT-23
R1: 22R; R_0402_1005Metric
R2: 10K; R_0402_1005Metric
U1: LCD_1.3_240x240_ST7789

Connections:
+3V3: C1.1, J1.7, U1.4 (VDD), U1.11 (RST)
+5V: C2.1, J1.8, U1.3 (LEDA)
/BL: J1.1, R2.2
/CS: J1.2, U1.8 (CS)
/DC: J1.5, U1.7 (DC)
/MOSI: J1.3, U1.10 (SDA)
/SCLK: J1.4, U1.9 (SCL)
GND: C1.2, C2.2, J1.6, J1.MP (MountPin), Q1.2 (E), U1.1 (GND), U1.5 (GND), U1.6 (GND), U1.12 (GND)
unnamed: R1.1, U1.2 (LEDK)
unnamed: Q1.3 (C), R1.2
unnamed: Q1.1 (B), R2.1

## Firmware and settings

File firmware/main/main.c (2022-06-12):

// Copyright 2018-2019 Espressif Systems (Shanghai) PTE LTD
//
// Licensed under the Apache License, Version 2.0 (the "License");
// you may not use this file except in compliance with the License.
// You may obtain a copy of the License at
//
//     http://www.apache.org/licenses/LICENSE-2.0
//
// Unless required by applicable law or agreed to in writing, software
// distributed under the License is distributed on an "AS IS" BASIS,
// WITHOUT WARRANTIES OR CONDITIONS OF ANY KIND, either express or implied.
// See the License for the specific language governing permissions and
// limitations under the License.


#include <stdio.h>
#include <stdlib.h>
#include <string.h>
#include "freertos/FreeRTOS.h"
#include "freertos/task.h"
#include "esp_system.h"

#include "driver/spi_master.h"
#include "esp_lcd_panel_io.h"
#include "esp_lcd_panel_vendor.h"
#include "esp_lcd_panel_ops.h"
#include "driver/gpio.h"

#include "wm8978.h"
static const char *TAG = "main";

#include "driver/gpio.h"
#include "driver/i2s.h"
#include "bsp_i2c.h"
#include "esp_err.h"
#include "esp_log.h"

/* Required for I2S driver workaround */
#include "esp_rom_gpio.h"
#include "hal/gpio_hal.h"
#include "hal/i2s_ll.h"

#define I2S_CONFIG_DEFAULT() { \
    .mode                   = I2S_MODE_MASTER | I2S_MODE_TX | I2S_MODE_RX, \
    .sample_rate            = sample_rate, \
    .bits_per_sample        = I2S_BITS_PER_SAMPLE_16BIT, \
    .channel_format         = I2S_CHANNEL_FMT_RIGHT_LEFT, \
    .communication_format   = I2S_COMM_FORMAT_STAND_I2S, \
    .intr_alloc_flags       = ESP_INTR_FLAG_LEVEL1, \
    .dma_buf_count          = 6, \
    .dma_buf_len            = 160, \
    .use_apll               = false, \
    .tx_desc_auto_clear     = true, \
    .fixed_mclk             = 0, \
    .mclk_multiple          = I2S_MCLK_MULTIPLE_DEFAULT, \
    .bits_per_chan          = I2S_BITS_PER_CHAN_16BIT, \
}

esp_err_t bsp_i2s_init(i2s_port_t i2s_num, uint32_t sample_rate)
{
    esp_err_t ret_val = ESP_OK;

    i2s_config_t i2s_config = I2S_CONFIG_DEFAULT();

    i2s_pin_config_t pin_config = {
        .bck_io_num = 13,
        .ws_io_num = 14,
        .data_out_num = 11,
        .data_in_num = 12,
        .mck_io_num = 10,
    };

    ret_val |= i2s_driver_install(i2s_num, &i2s_config, 0, NULL);
    ret_val |= i2s_set_pin(i2s_num, &pin_config);
    ret_val |= i2s_zero_dma_buffer(i2s_num);
// ESP_LOGW(TAG, "set pdm");
    // ret_val |= i2s_set_pdm_rx_down_sample(i2s_num, I2S_PDM_DSR_16S);

    return ret_val;
}

esp_err_t bsp_i2s_deinit(i2s_port_t i2s_num)
{
    esp_err_t ret_val = ESP_OK;

    ret_val |= i2s_stop(I2S_NUM_0);
    ret_val |= i2s_driver_uninstall(i2s_num);

    return ret_val;
}

#define EXAMPLE_LCD_PIXEL_CLOCK_HZ     (40 * 1000 * 1000)
#define EXAMPLE_LCD_BK_LIGHT_ON_LEVEL  0
#define EXAMPLE_LCD_BK_LIGHT_OFF_LEVEL !EXAMPLE_LCD_BK_LIGHT_ON_LEVEL
#define EXAMPLE_PIN_NUM_DATA0          21
#define EXAMPLE_PIN_NUM_PCLK           18
#define EXAMPLE_PIN_NUM_CS             47
#define EXAMPLE_PIN_NUM_DC             48
#define EXAMPLE_PIN_NUM_RST            -1
#define EXAMPLE_PIN_NUM_BK_LIGHT       -1

// The pixel number in horizontal and vertical
#define EXAMPLE_LCD_H_RES              240
#define EXAMPLE_LCD_V_RES              320
// Bit number used to represent command and parameter
#define EXAMPLE_LCD_CMD_BITS           8
#define EXAMPLE_LCD_PARAM_BITS         8

esp_lcd_panel_handle_t panel_handle = NULL;
static esp_lcd_panel_io_handle_t io_handle = NULL;

static esp_err_t _spi_1line_lcd_init(void)
{
    esp_err_t ret_val = ESP_OK;

    // gpio_config_t bk_gpio_config = {
    //         .mode = GPIO_MODE_OUTPUT,
    //         .pin_bit_mask = BIT64(47)
    //     };
    //     ESP_ERROR_CHECK(gpio_config(&bk_gpio_config));
    //     gpio_set_level(47, 1);vTaskDelay(pdMS_TO_TICKS(200));
    //     gpio_set_level(47, 0);vTaskDelay(pdMS_TO_TICKS(200));
    //     gpio_set_level(47, 1);vTaskDelay(pdMS_TO_TICKS(200));

    spi_bus_config_t buscfg = {
        .sclk_io_num = EXAMPLE_PIN_NUM_PCLK,
        .mosi_io_num = EXAMPLE_PIN_NUM_DATA0,
        .miso_io_num = GPIO_NUM_NC,
        .quadwp_io_num = GPIO_NUM_NC,
        .quadhd_io_num = GPIO_NUM_NC,
        .max_transfer_sz = EXAMPLE_LCD_H_RES * EXAMPLE_LCD_V_RES * sizeof(uint16_t)
    };
    ret_val |= spi_bus_initialize(SPI2_HOST, &buscfg, SPI_DMA_CH_AUTO);

    esp_lcd_panel_io_spi_config_t io_config = {
        .dc_gpio_num = EXAMPLE_PIN_NUM_DC,
        .cs_gpio_num = EXAMPLE_PIN_NUM_CS,
        .pclk_hz = EXAMPLE_LCD_PIXEL_CLOCK_HZ,
        .spi_mode = 0,
        .trans_queue_depth = 10,
        .lcd_cmd_bits = EXAMPLE_LCD_CMD_BITS,
        .lcd_param_bits = EXAMPLE_LCD_PARAM_BITS,
        .user_ctx = NULL,
        // .flags.dc_as_cmd_phase = 1,
    };
    ret_val |= esp_lcd_new_panel_io_spi((esp_lcd_spi_bus_handle_t) SPI2_HOST, &io_config, &io_handle);

    esp_lcd_panel_dev_config_t panel_config = {
        .reset_gpio_num = EXAMPLE_PIN_NUM_RST,
        .color_space = ESP_LCD_COLOR_SPACE_RGB,
        .bits_per_pixel = 16,
    };
    ESP_ERROR_CHECK(esp_lcd_new_panel_st7789(io_handle, &panel_config, &panel_handle));
    ESP_ERROR_CHECK(esp_lcd_panel_reset(panel_handle));
    ESP_ERROR_CHECK(esp_lcd_panel_init(panel_handle));
    esp_lcd_panel_disp_off(panel_handle, 0);
    esp_lcd_panel_invert_color(panel_handle, 1);

    if (EXAMPLE_PIN_NUM_BK_LIGHT >= 0) {
        gpio_config_t bk_gpio_config = {
            .mode = GPIO_MODE_OUTPUT,
            .pin_bit_mask = 1ULL << EXAMPLE_PIN_NUM_BK_LIGHT
        };
        ESP_ERROR_CHECK(gpio_config(&bk_gpio_config));
        ESP_LOGI(TAG, "Turn on LCD backlight");
        gpio_set_level(EXAMPLE_PIN_NUM_BK_LIGHT, EXAMPLE_LCD_BK_LIGHT_ON_LEVEL);
    }

    return ESP_OK;
}

static void screen_clear(int color)
{
    int w = 320;
    int h = 240;
    uint16_t *buffer = malloc(w * sizeof(uint16_t));
    if (NULL == buffer) {
        return;
    } else {
        for (size_t i = 0; i < w; i++) {
            buffer[i] = color;
        }

        for (int y = 0; y < h; y++) {
            esp_lcd_panel_draw_bitmap(panel_handle, 0, y, w, y + 1, buffer);
        }

        free(buffer);
    }
}


void app_main()
{
    esp_err_t ret;
    ESP_LOGI(TAG, "Compile time: %s %s", __DATE__, __TIME__);
    /* Initialize NVS. */
    esp_err_t err = nvs_flash_init();
    if (err == ESP_ERR_NVS_NO_FREE_PAGES || err == ESP_ERR_NVS_NEW_VERSION_FOUND) {
        ESP_ERROR_CHECK(nvs_flash_erase());
        err = nvs_flash_init();
    }
    ESP_ERROR_CHECK(err);
    ESP_ERROR_CHECK(settings_read_parameter_from_nvs());

    _spi_1line_lcd_init();
    screen_clear(0xdd);

    bsp_i2s_init(I2S_NUM_0, 16000);
    ESP_ERROR_CHECK(bsp_i2c_init(I2C_NUM_0, 100000, 16, 17));

    bsp_i2c_probe();

    vTaskDelay(pdMS_TO_TICKS(500));

    WM8978_Init();
    // WM8978_PlayMode();
    WM8978_RecoMode();

    // WM8978_HPvol_Set(32, 32);
    // WM8978_SPKvol_Set(40);

    ESP_ERROR_CHECK(bsp_spiffs_init("storage", "/spiffs", 2));
    // ESP_ERROR_CHECK(bsp_spiffs_init("model", "/srmodel", 4));

    // while (1)
    // {WM8978_SPKvol_Set(60);
    //     esp_err_t sr_echo_play(char audio_file[]);
    //     sr_echo_play("/spiffs/echo_cn_wake.wav");
    //     vTaskDelay(pdMS_TO_TICKS(500));
    // }
    ESP_LOGI(TAG, "speech recognition start");
    // app_sr_start(false);

    void ap_start(void);
    ap_start();
    ESP_LOGI(TAG, "exit");
}

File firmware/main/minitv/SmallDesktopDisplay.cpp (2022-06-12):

/* *****************************************************************
 * 
 * SmallDesktopDisplay
 *    小型桌面显示器
 * 
 * 原  作  者：Misaka
 * 修      改：微车游
 * 讨  论  群：811058758、887171863
 * 创 建 日 期：2021.07.19
 * 最后更改日期：2021.09.18
 * 更 改 说 明：V1.1添加串口调试，波特率115200\8\n\1；增加版本号显示。
 *            V1.2亮度和城市代码保存到EEPROM，断电可保存
 *            V1.3.1 更改smartconfig改为WEB配网模式，同时在配网的同时增加亮度、屏幕方向设置。
 *            V1.3.2 增加wifi休眠模式，仅在需要连接的情况下开启wifi，其他时间关闭wifi。增加wifi保存至eeprom（目前仅保存一组ssid和密码）
 *            V1.3.3  修改WiFi保存后无法删除的问题。目前更改为使用串口控制，输入 0x05 重置WiFi数据并重启。
 *                    增加web配网以及串口设置天气更新时间的功能。
 *            V1.3.4  修改web配网页面设置，将wifi设置页面以及其余设置选项放入同一页面中。
 *                    增加web页面设置是否使用DHT传感器。（使能DHT后才可使用）
 *            V1.4    增加web服务器，使用web网页进行设置。由于使用了web服务器，无法开启WiFi休眠。
 *                    注意，此版本中的DHT11传感器和太空人图片选择可以通过web网页设置来进行选择，无需通过使能标志来重新编译。
 * 
 * 引 脚 分 配： SCK  GPIO14
 *             MOSI  GPIO13
 *             RES   GPIO2
 *             DC    GPIO0
 *             LCDBL GPIO5
 *             
 *             增加DHT11温湿度传感器，传感器接口为 GPIO 12
 * 
 *    感谢群友 @你别失望  提醒发现WiFi保存后无法重置的问题，目前已解决。详情查看更改说明！
 * *****************************************************************/
#define Version  "SDD V1.4"
/* *****************************************************************
 *  库文件、头文件
 * *****************************************************************/


/* *****************************************************************
 *  配置使能位
 * *****************************************************************/
//WEB配网使能标志位----WEB配网打开后会默认关闭smartconfig功能
#define WM_EN   1


#if WM_EN
#include <WiFiManager.h>
//WiFiManager 参数
WiFiManager wm; // global wm instance
// WiFiManagerParameter custom_field; // global param ( for non blocking w params )
#endif








/* *****************************************************************
 *  参数设置
 * *****************************************************************/

struct config_type
{
  char stassid[32];//定义配网得到的WIFI名长度(最大32字节)
  char stapsw[64];//定义配网得到的WIFI密码长度(最大64字节)
};

//---------------修改此处""内的信息--------------------
//如开启WEB配网则可不用设置这里的参数，前一个为wifi ssid，后一个为密码
config_type wificonf ={{""},{""}};






//函数声明
time_t getNtpTime();
void digitalClockDisplay(int reflash_en);
void printDigits(int digits);
String num2str(int digits);
void sendNTPpacket(IPAddress &address);
void LCD_reflash(int en);
void savewificonfig();
void readwificonfig();
void deletewificonfig();
#if WebSever_EN
void Web_Sever_Init();
void Web_Sever();
#endif
void saveCityCodetoEEP(int * citycode);
void readCityCodefromEEP(int * citycode);



#if WebSever_EN
//web网站相关函数
//web设置页面
void handleconfig()
{
  String msg;
  int web_cc,web_setro,web_lcdbl,web_upt,web_dhten;

  if (server.hasArg("web_ccode") || server.hasArg("web_bl") || \
      server.hasArg("web_upwe_t") || server.hasArg("web_DHT11_en") || server.hasArg("web_set_rotation")) 
  {
    web_cc    = server.arg("web_ccode").toInt();
    web_setro = server.arg("web_set_rotation").toInt();
    web_lcdbl = server.arg("web_bl").toInt();
    web_upt   = server.arg("web_upwe_t").toInt();
    web_dhten = server.arg("web_DHT11_en").toInt();
    Serial.println("");
    if(web_cc>=101000000 && web_cc<=102000000) 
    {
      saveCityCodetoEEP(&web_cc);
      readCityCodefromEEP(&web_cc);
      cityCode = web_cc;
      Serial.print("城市代码:");
      Serial.println(web_cc);
    }
    if(web_lcdbl>0 && web_lcdbl<=100)
    {
      EEPROM.write(BL_addr, web_lcdbl);//亮度地址写入亮度值
      EEPROM.commit();//保存更改的数据
      delay(5);
      LCD_BL_PWM = EEPROM.read(BL_addr); 
      delay(5);
      Serial.printf("亮度调整为：");
      analogWrite(LCD_BL_PIN, 1023 - (LCD_BL_PWM*10));
      Serial.println(LCD_BL_PWM);
      Serial.println("");
    }
    if(web_upt > 0 && web_upt <= 60)
    {
      EEPROM.write(UpWeT_addr, web_upt);//亮度地址写入亮度值
      EEPROM.commit();//保存更改的数据
      delay(5);
      updateweater_time = web_upt;
      Serial.print("天气更新时间（分钟）:");
      Serial.println(web_upt);
    }

    EEPROM.write(DHT_addr, web_dhten);
    EEPROM.commit();//保存更改的数据
    delay(5);
    if(web_dhten != DHT_img_flag)
    {
      DHT_img_flag = web_dhten;
      tft.fillScreen(0x0000);
      LCD_reflash(1);//屏幕刷新程序
      UpdateWeater_en = 1;
      TJpgDec.drawJpg(15,183,temperature, sizeof(temperature));  //温度图标
      TJpgDec.drawJpg(15,213,humidity, sizeof(humidity));  //湿度图标
    }
    Serial.print("DHT Sensor Enable： ");
    Serial.println(DHT_img_flag);

    
    EEPROM.write(Ro_addr, web_setro);
    EEPROM.commit();//保存更改的数据
    delay(5);
    if(web_setro != LCD_Rotation)
    {
      LCD_Rotation = web_setro;
      tft.setRotation(LCD_Rotation);
      tft.fillScreen(0x0000);
      LCD_reflash(1);//屏幕刷新程序
      UpdateWeater_en = 1;
      TJpgDec.drawJpg(15,183,temperature, sizeof(temperature));  //温度图标
      TJpgDec.drawJpg(15,213,humidity, sizeof(humidity));  //湿度图标
    }
    Serial.print("LCD Rotation:");
    Serial.println(LCD_Rotation);
  }

  //网页界面代码段
  String content = "<html><style>html,body{ background: #1aceff; color: #fff; font-size: 10px;}</style>";
        content += "<body><form action='/' method='POST'><br><div>SDD Web Config</div><br>";
        content += "City Code:<br><input type='text' name='web_ccode' placeholder='city code'><br>";
        content += "<br>Back Light(1-100):(default:50)<br><input type='text' name='web_bl' placeholder='10'><br>";
        content += "<br>Weather Update Time:(default:10)<br><input type='text' name='web_upwe_t' placeholder='10'><br>";
        #if DHT_EN
        content += "<br>DHT Sensor Enable  <input type='radio' name='web_DHT11_en' value='0'checked> DIS \
                                          <input type='radio' name='web_DHT11_en' value='1'> EN<br>";
        #endif
        content += "<br>LCD Rotation<br>\
                    <input type='radio' name='web_set_rotation' value='0' checked> USB Down<br>\
                    <input type='radio' name='web_set_rotation' value='1'> USB Right<br>\
                    <input type='radio' name='web_set_rotation' value='2'> USB Up<br>\
                    <input type='radio' name='web_set_rotation' value='3'> USB Left<br>";
        content += "<br><div><input type='submit' name='Save' value='Save'></form></div>" + msg + "<br>";
        content += "By WCY<br>";
        content += "</body></html>";
  server.send(200, "text/html", content);
}

//no need authentication
void handleNotFound() {
  String message = "File Not Found\n\n";
  message += "URI: ";
  message += server.uri();
  message += "\nMethod: ";
  message += (server.method() == HTTP_GET) ? "GET" : "POST";
  message += "\nArguments: ";
  message += server.args();
  message += "\n";
  for (uint8_t i = 0; i < server.args(); i++) {
    message += " " + server.argName(i) + ": " + server.arg(i) + "\n";
  }
  server.send(404, "text/plain", message);
}
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

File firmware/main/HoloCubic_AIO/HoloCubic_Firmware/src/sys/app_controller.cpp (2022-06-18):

#include "Arduino.h"
#include "app_controller.h"
#include "app_controller_gui.h"
#include "common.h"

static const char *TAG="app_ctrl";

const char *app_event_type_info[] = {"APP_MESSAGE_WIFI_CONN", "APP_MESSAGE_WIFI_AP",
                                     "APP_MESSAGE_WIFI_ALIVE", "APP_MESSAGE_WIFI_DISCONN",
                                     "APP_MESSAGE_UPDATE_TIME", "APP_MESSAGE_MQTT_DATA",
                                     "APP_MESSAGE_GET_PARAM", "APP_MESSAGE_SET_PARAM",
                                     "APP_MESSAGE_READ_CFG", "APP_MESSAGE_WRITE_CFG",
                                     "APP_MESSAGE_NONE"
                                    };

volatile static bool isRunEventDeal = false;

static TimerHandle_t xTimerEventDeal; // 事件处理定时器

LV_IMG_DECLARE(app_loading);

void eventDealHandle(TimerHandle_t xTimer)
{
    isRunEventDeal = true;
}

AppController::AppController(const char *name)
{
    strncpy(this->name, name, APP_CONTROLLER_NAME_LEN);
    app_num = 0;
    app_exit_flag = 0;
    cur_app_index = 0;
    pre_app_index = 0;
    // appList = new APP_OBJ[APP_MAX_NUM];
    m_wifi_status = false;
    m_preWifiReqMillis = millis();

    // 定义一个事件处理定时器
    xTimerEventDeal = xTimerCreate("Event Deal",
                                   300 / portTICK_PERIOD_MS,
                                   pdTRUE, (void *)0, eventDealHandle);
    // 启动事件处理定时器
    xTimerStart(xTimerEventDeal, 0);
}

void AppController::init(void)
{
    // 设置CPU主频
    if (1 == this->sys_cfg.power_mode) {
        setCpuFrequencyMhz(240);
    } else {
        setCpuFrequencyMhz(80);
    }
    // uint32_t freq = getXtalFrequencyMhz(); // In MHz
    Serial.print(F("CpuFrequencyMhz: "));
    Serial.println(getCpuFrequencyMhz());

    app_control_gui_init();
    appList[0] = new APP_OBJ();
    appList[0]->app_image = &app_loading;
    appList[0]->app_name = "None";
    appTypeList[0] = APP_TYPE_REAL_TIME;
    app_control_display_scr(appList[cur_app_index]->app_image,
                            appList[cur_app_index]->app_name,
                            LV_SCR_LOAD_ANIM_NONE, true);
    // Display();
}

void AppController::Display()
{
    // appList[0].app_image = &app_loading;
    app_control_display_scr(appList[cur_app_index]->app_image,
                            appList[cur_app_index]->app_name,
                            LV_SCR_LOAD_ANIM_NONE, true);
}

AppController::~AppController()
{
    // rgb_thread_del();
}

int AppController::app_is_legal(const APP_OBJ *app_obj)
{
    // APP的合法性检测
    if (NULL == app_obj) {
        return 1;
    }
    if (APP_MAX_NUM <= app_num) {
        return 2;
    }
    return 0;
}

// 将APP安装到app_controller中
int AppController::app_install(APP_OBJ *app, APP_TYPE app_type)
{
    int ret_code = app_is_legal(app);
    if (0 != ret_code) {
        return ret_code;
    }

    appList[app_num] = app;
    appTypeList[app_num] = app_type;
    ++app_num;
    return 0; // 安装成功
}

// 将APP的后台任务从任务队列中移除(自能通过APP退出的时候，移除自身的后台任务)
int AppController::remove_backgroud_task(void)
{
    return 0; // 安装成功
}

// 将APP从app_controller中卸载（删除）
int AppController::app_uninstall(const APP_OBJ *app)
{
    // todo
    return 0;
}

int AppController::main_process(APP_ACTIVE_TYPE active)
{
    this->act_info = active;
    if (isRunEventDeal) {
        isRunEventDeal = false;
        // 扫描事件
        this->req_event_deal();
    }

    // wifi自动关闭(在节能模式下)
    if (0 == sys_cfg.power_mode && true == m_wifi_status && doDelayMillisTime(WIFI_LIFE_CYCLE, &m_preWifiReqMillis, false)) {
        send_to(CTRL_NAME, CTRL_NAME, APP_MESSAGE_WIFI_DISCONN, 0, NULL);
    }

    if (0 == app_exit_flag) {
        // 当前没有进入任何app
        lv_scr_load_anim_t anim_type = LV_SCR_LOAD_ANIM_NONE;
        if (APP_ACTIVE_TYPE::APP_TURN_LEFT == active) {
            anim_type = LV_SCR_LOAD_ANIM_MOVE_RIGHT;
            pre_app_index = cur_app_index;
            cur_app_index = (cur_app_index + 1) % app_num;
            Serial.println(String("Current App: ") + appList[cur_app_index]->app_name);
        } else if (APP_ACTIVE_TYPE::APP_TURN_RIGHT == active) {
            anim_type = LV_SCR_LOAD_ANIM_MOVE_LEFT;
            pre_app_index = cur_app_index;
            // 以下等效与 processId = (processId - 1 + APP_NUM) % 4;
            // +3为了不让数据溢出成负数，而导致取模逻辑错误
            cur_app_index = (cur_app_index - 1 + app_num) % app_num; // 此处的3与p_processList的长度一致
            Serial.println(String("Current App: ") + appList[cur_app_index]->app_name);
        } else if (APP_ACTIVE_TYPE::APP_GO_FORWORD == active) {
            app_exit_flag = 1; // 进入app
            if (NULL != appList[cur_app_index]->app_init) {
                (*(appList[cur_app_index]->app_init))(this); // 执行APP初始化
            }
        }

        if (APP_ACTIVE_TYPE::APP_GO_FORWORD != active) { // && UNKNOWN != active
            app_control_display_scr(appList[cur_app_index]->app_image,
                                    appList[cur_app_index]->app_name,
                                    anim_type, false);
            delay(300);
        }
    } else {
        // 运行APP进程 等效于把控制权交给当前APP
        (*(appList[cur_app_index]->main_process))(this);
    }

    return 0;
}

APP_OBJ *AppController::getAppByName(const char *name)
{
    for (int pos = 0; pos < app_num; ++pos) {
        if (!strcmp(name, appList[pos]->app_name)) {
            return appList[pos];
        }
    }

    return NULL;
}

int AppController::getAppIdxByName(const char *name)
{
    for (int pos = 0; pos < app_num; ++pos) {
        if (!strcmp(name, appList[pos]->app_name)) {
            return pos;
        }
    }

    return -1;
}

// 通信中心（消息转发）
int AppController::send_to(const char *from, const char *to,
                           APP_MESSAGE_TYPE type, void *message,
                           void *ext_info)
{
    APP_OBJ *fromApp = getAppByName(from); // 来自谁 有可能为空
    APP_OBJ *toApp = getAppByName(to);     // 发送给谁 有可能为空
    if (type <= APP_MESSAGE_MQTT_DATA) {
        // 更新事件的请求者
        if (eventList.size() > EVENT_LIST_MAX_LENGTH) {
            return 1;
        }
        // 发给控制器的消息(目前都是wifi事件)
        EVENT_OBJ new_event = {fromApp, type, message, 3, 0, 0};
        eventList.push_back(new_event);
        Serial.print("[EVENT]\tAdd -> " + String(app_event_type_info[type]));
        ESP_LOGI(TAG, "\tEventList Size: %d", eventList.size());
    } else {
        // 各个APP之间通信的消息
        if (NULL != toApp) {
            ESP_LOGI(TAG, "[Massage]From %s To %s", String(fromApp->app_name).c_str(),  String(toApp->app_name).c_str());
            if (NULL != toApp->message_handle) {
                toApp->message_handle(from, to, type, message, ext_info);
            }
        } else if (!strcmp(to, CTRL_NAME)) {
            ESP_LOGI(TAG, "[Massage]From %s To %s", String(fromApp->app_name).c_str(),  CTRL_NAME);
            deal_config(type, (const char *)message, (char *)ext_info);
        }
    }
    return 0;
}
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

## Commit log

2022-06-09 add firmware
    [partitions.csv]
2022-06-09 hw: update
    [holocubic.kicad_pcb, holocubic.kicad_sch]
2022-06-09 hw: v1.0
    [HRO_TYPE-C-31-M-12.step, MEMS_MIC_2.75x1.85x0.95mm.STEP, USB-AM-S-F-B-TH.STEP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]
2022-06-09 add speech recognition
    [partitions.csv]
2022-06-09 add board support
    [partitions.csv]
2022-06-12 add aio
    [partitions.csv]
2022-06-12 update aio
    [partitions.csv]
2022-06-12 add arduino-esp32
    [app3M_fat9M_16MB.csv, bare_minimum_2MB.csv, default.csv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]
2022-06-18 sw: update
    [holocubic.kicad_pcb]
2022-06-18 hw: v1.1
    [BOM-holocubic.csv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]
2022-06-18 hw: add lcd sub board
    [BOM-holocubic.csv, BOM-screen_sub_board.csv, HRO_TYPE-C-31-M-12.step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]
2022-07-22 update sch
    [holocubic.kicad_sch]
